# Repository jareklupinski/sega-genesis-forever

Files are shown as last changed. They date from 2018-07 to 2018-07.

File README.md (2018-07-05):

# sega-genesis-forever
A Standalone Sega Genesis music player using native hardware

Using an ATSAMD21 microcontroller, this gadget reads Sega Genesis VGM files from a microSD card and plays them back using the same sound chips that were used in the original Sega Genesis. Even the audio path is cloned from original schematics!

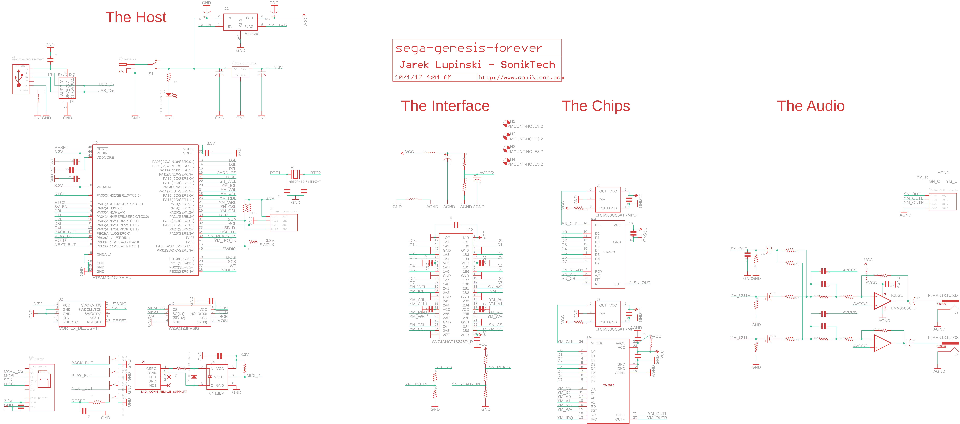
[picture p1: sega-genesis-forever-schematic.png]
schematic

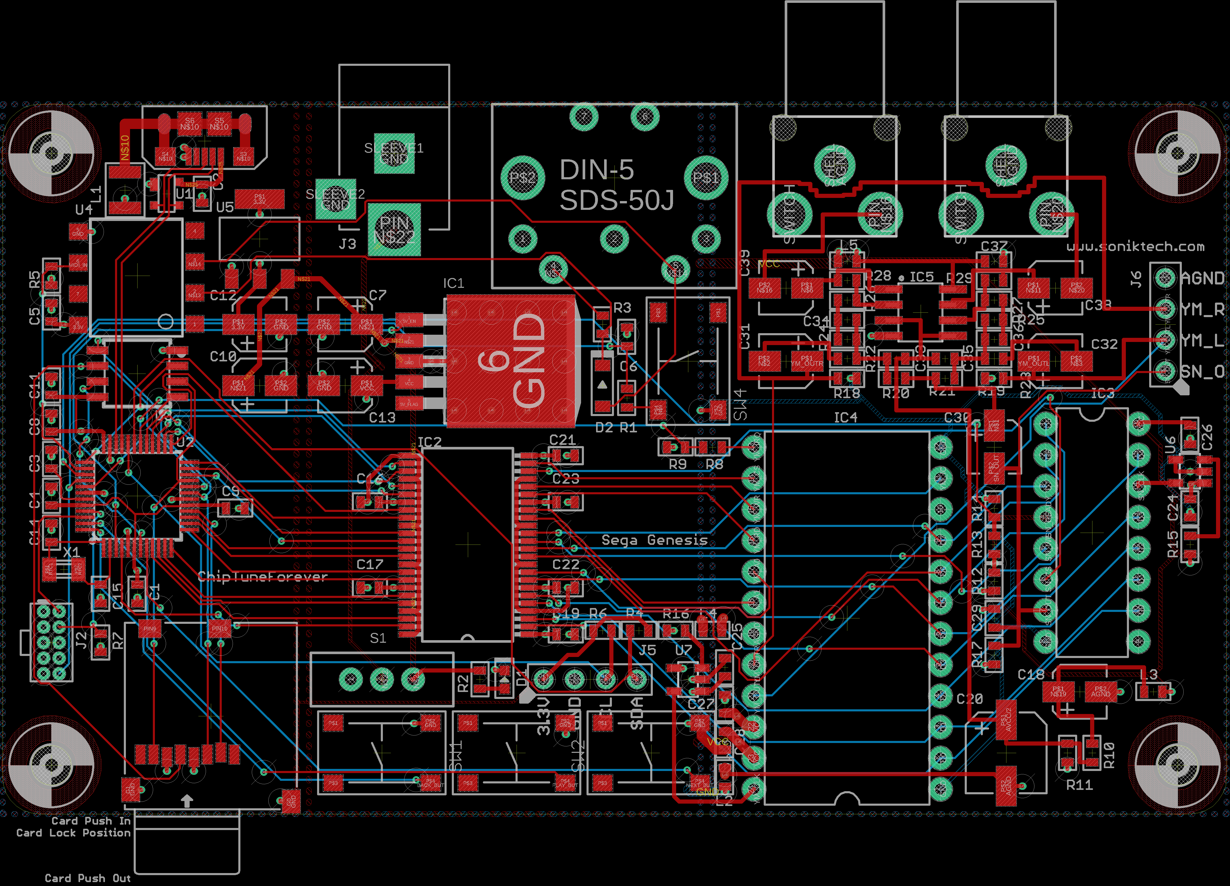
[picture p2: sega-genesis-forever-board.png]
board


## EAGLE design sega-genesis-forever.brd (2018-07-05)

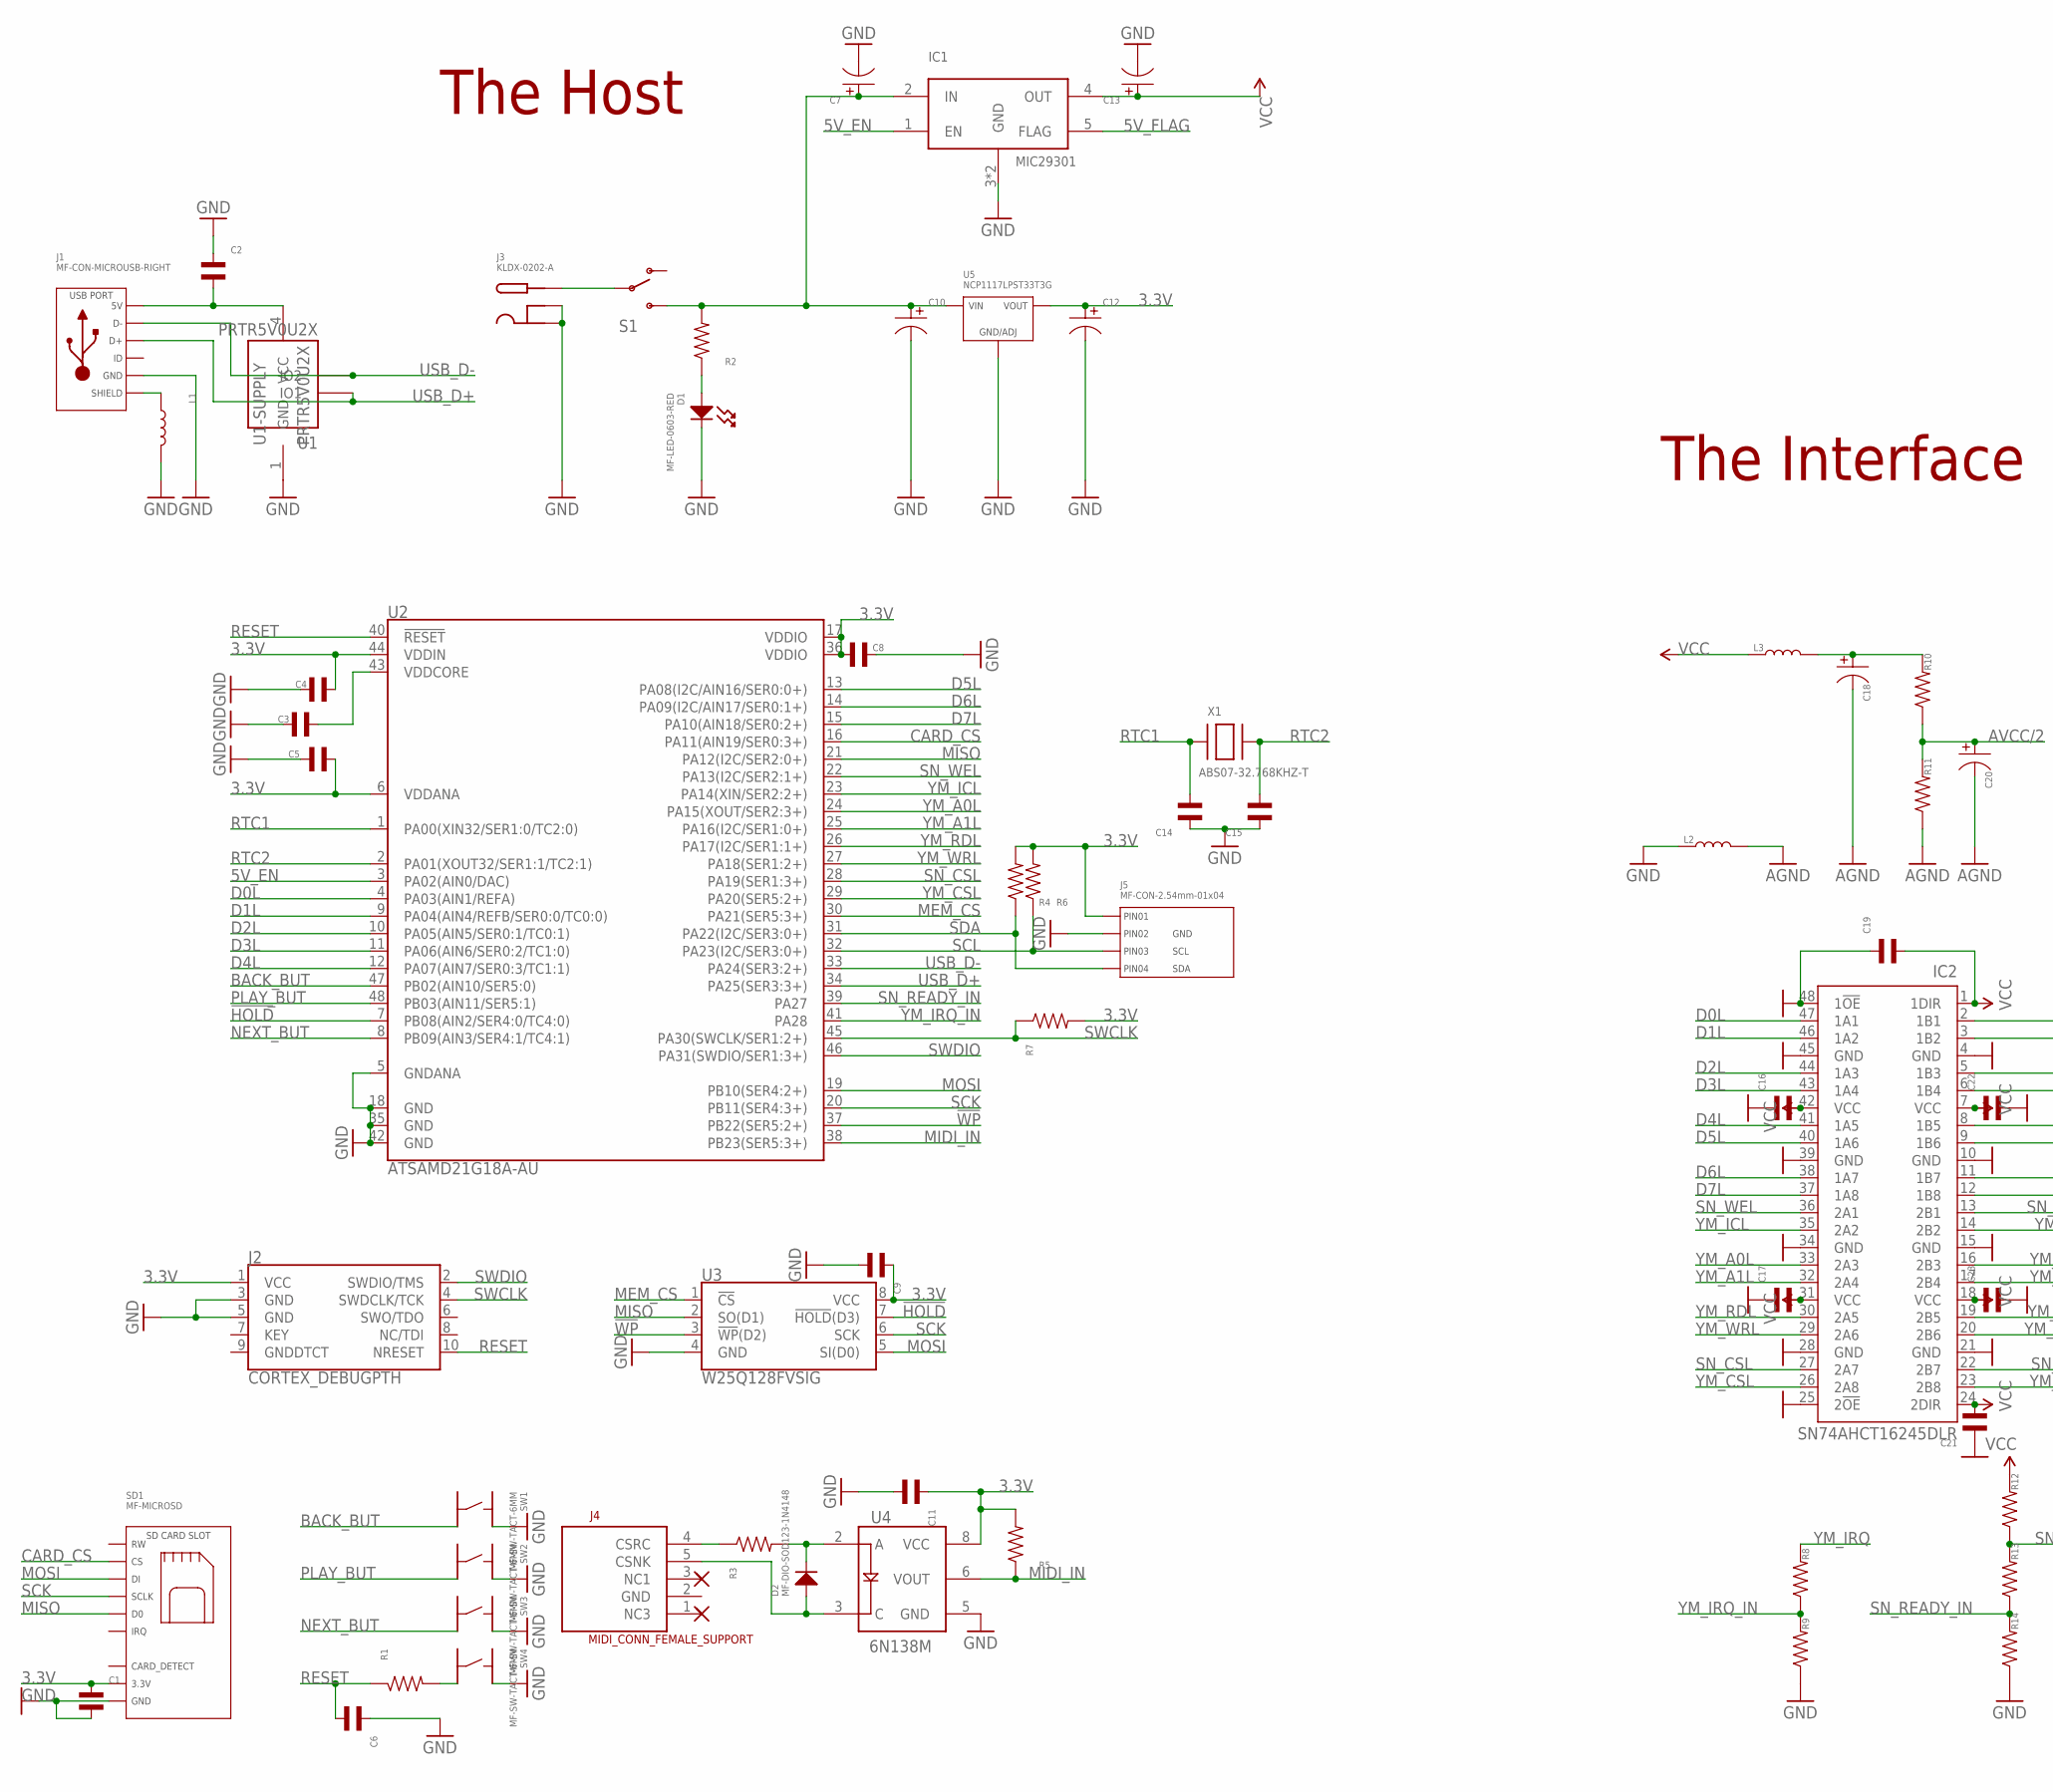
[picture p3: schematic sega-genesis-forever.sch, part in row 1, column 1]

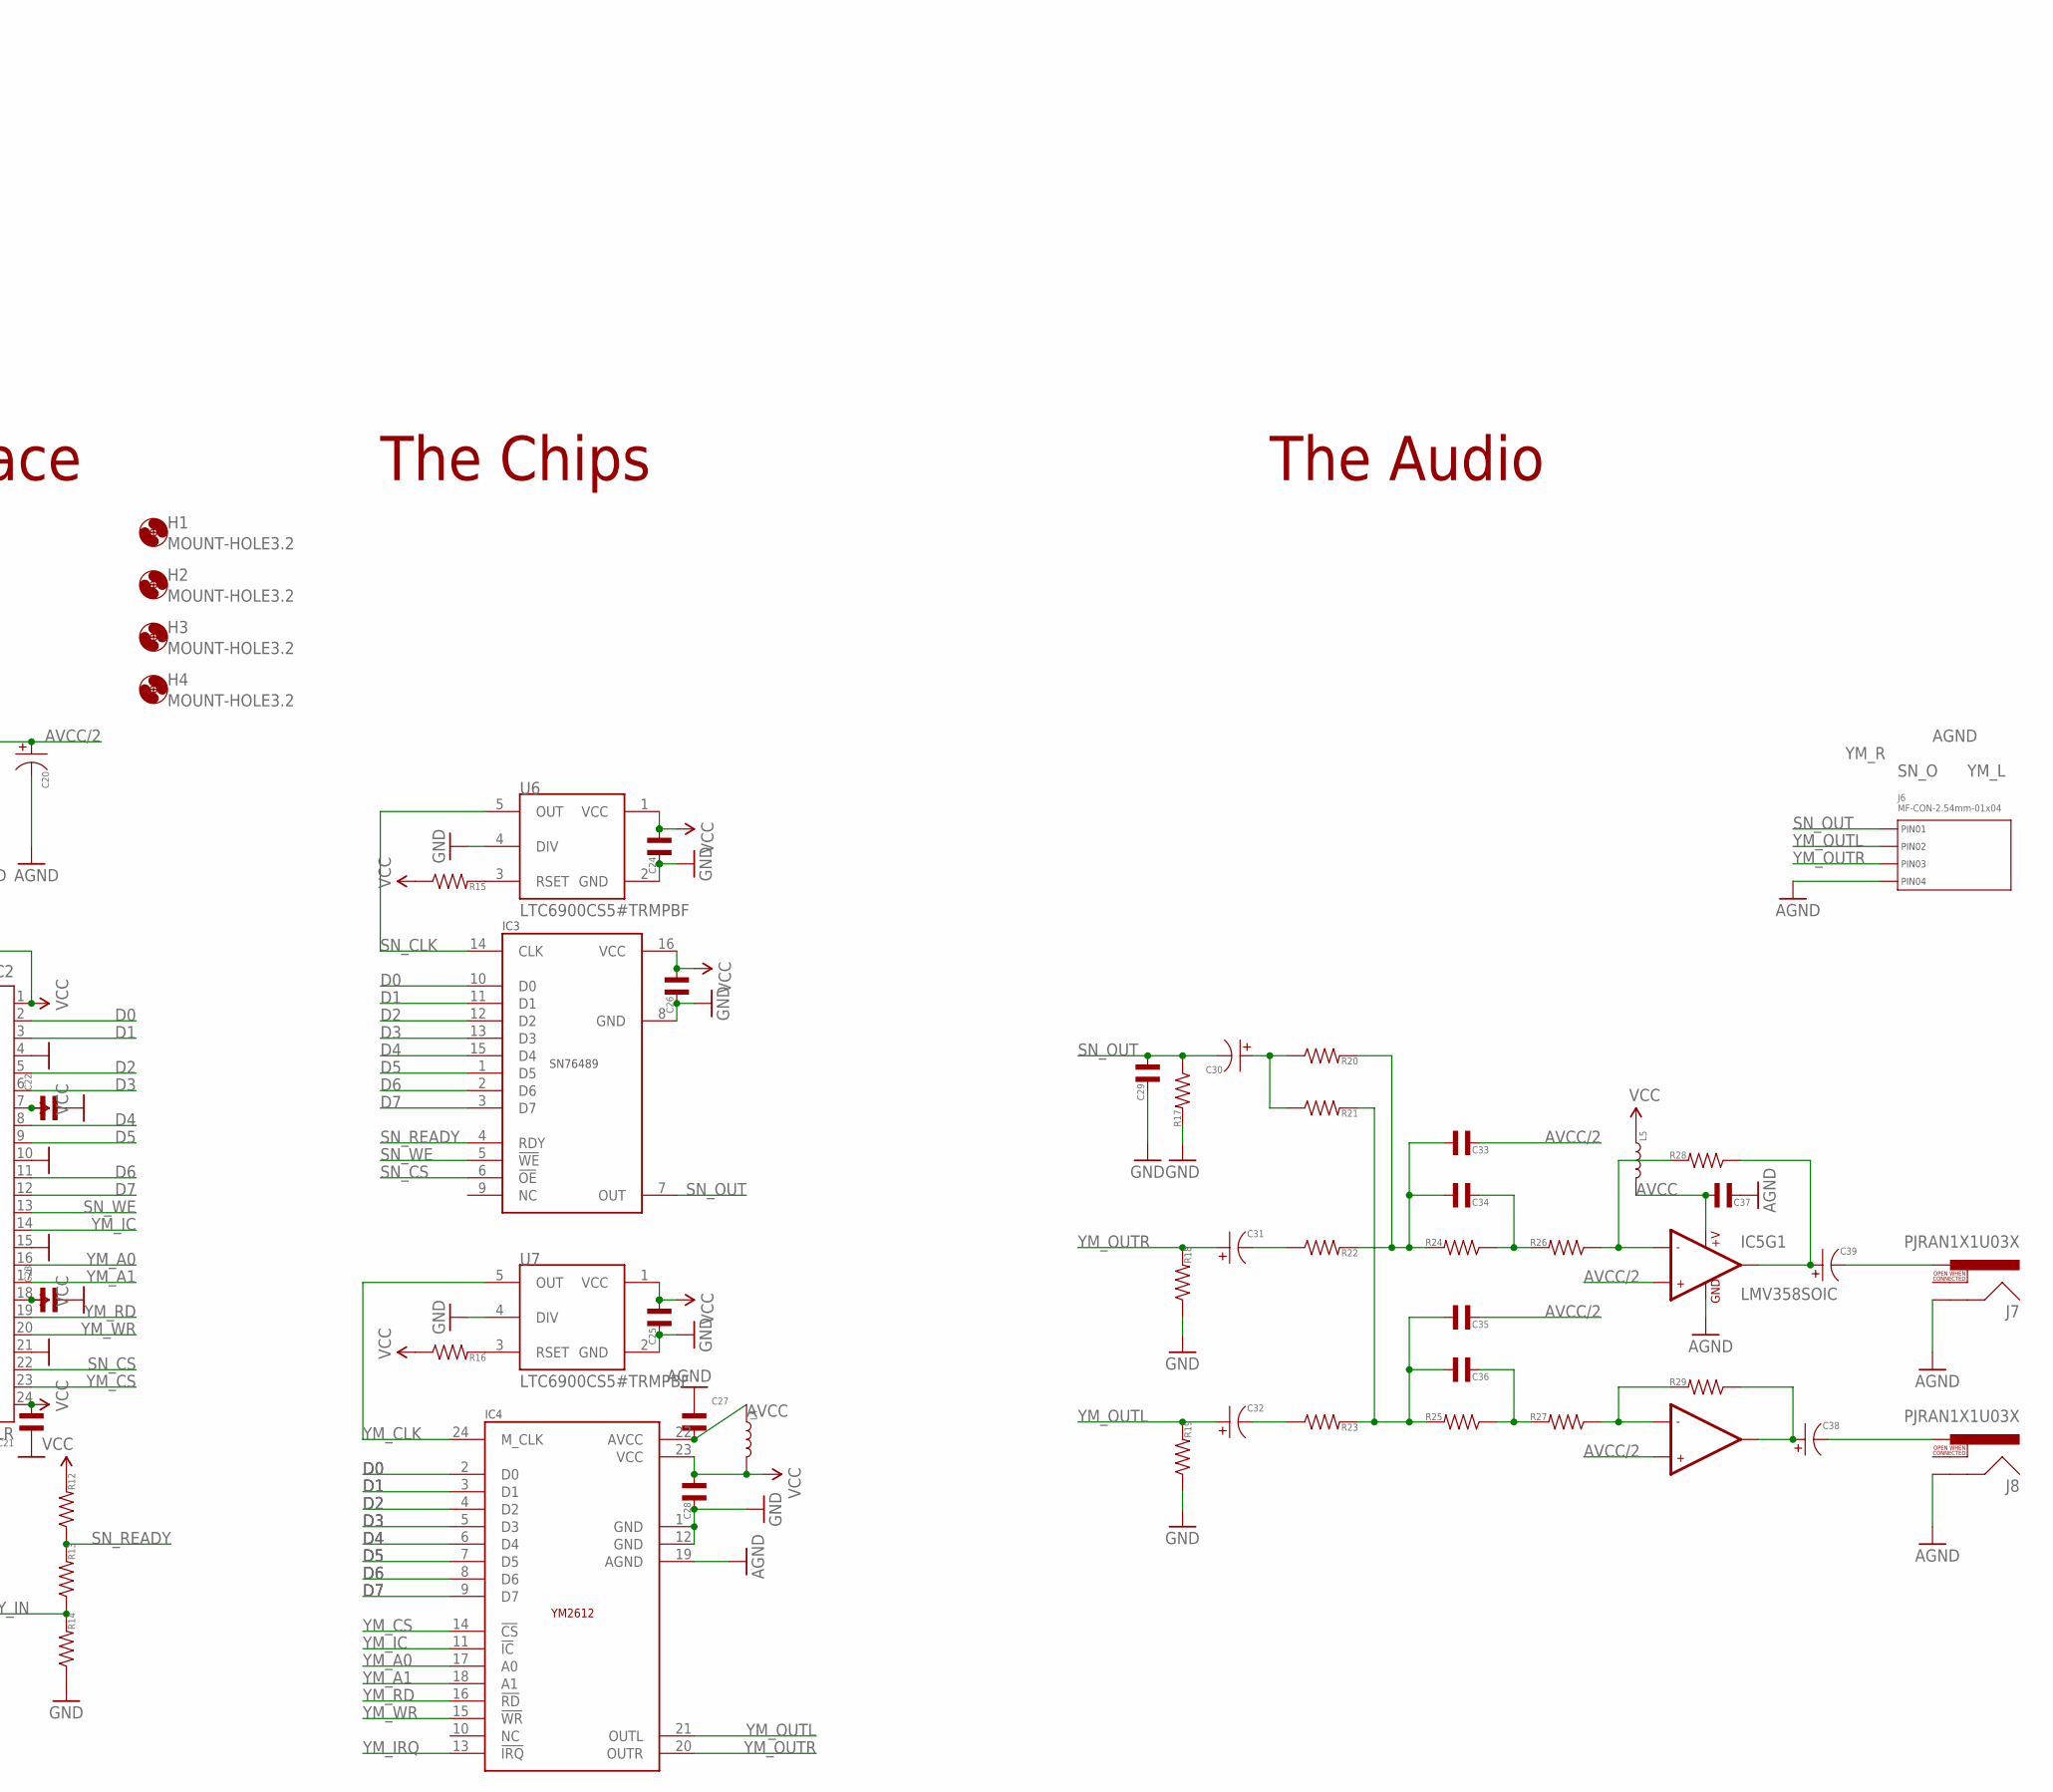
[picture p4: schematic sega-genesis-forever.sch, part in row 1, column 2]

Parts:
C1, C2, C3, C4, C5, C6, C8, C9, C11, C14, C15, C16, C17, C19, C21, C22, C23, C24, C25, C26, C27, C28, C29, C33, C34, C35, C36, C37: CAPACITOR_NP_0603; C0603
C7, C10, C12, C13, C18, C30, C31, C32, C38, C39: CAPACITOR_P_4MM; CP4MM
C20: CAPACITOR_P_6.3MM; CP6.3MM
D1: MF-LED-0603-RED; LED0603
D2: MF-DIO-SOD123-1N4148; SOD-123
H1, H2, H3, H4: MOUNT-HOLE3.2; 3,2
IC1: MIC29301; TO263-5
IC2: SN74AHCT16245DLR; DL_R-PDSO-G48
IC3: ED16DT; DIL16-EZ
IC4: ED24DT; DIL24-EZ
IC5: LMV358SOIC; SO08
J1: MF-CON-MICROUSB-RIGHT; MICROUSB-RIGHT
J2: CORTEX_DEBUGPTH; 2X5-PTH-1.27MM
J3: KLDX-0202-A; DC_PWR_JACK
J4: MIDI_CONN_FEMALE_SUPPORT; DIN_5_FEMALE_SUPPORT
J5, J6: MF-CON-2.54mm-01x04; PTH_2.54MM_01X04
J7, J8: PJRAN1X1U03X; RCA
L1: INDUCTOR_1210; L1210
L2, L3, L4, L5: INDUCTOR_0603; L0603
R1, R2, R3, R4, R5, R6, R7, R8, R9, R10, R11, R12, R13, R14, R15, R16, R17, R18, R19, R20, R21, R22, R23, R24, R25, R26, R27, R28, R29: RESISTOR_0603; R0603
S1: SWITCH-SPDTPTH; SWITCH-SPDT
SD1: MF-MICROSD
SW1, SW2, SW3, SW4: MF-SW-TACT-6MM; TACT6MM
U1: PRTR5V0U2X; SOT-143B
U2: ATSAMD21G18A-AU; TQFP-48
U3: W25Q128FVSIG; SOIC-8
U4: 6N138M; 8-SMD
U5: NCP1117LPST33T3G; SOT-223-3
U6, U7: LTC6900CS5#TRMPBF; TSOT23-5L
X1: ABS07-32.768KHZ-T; XTAL3215

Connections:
3.3V: C1.P$1, C4.P$2, C5.P$2, C8.P$2, C9.P$1, C11.P$1, C12.P$1, J2.1 (VCC), J5.P$1 (PIN1), R4.P$2, R5.P$2, R6.P$2, R7.P$2, SD1.PIN4 (3.3V), U2.6 (VDDANA), U2.17 (VDDIO), U2.36 (VDDIO), U2.44 (VDDIN), U3.8 (VCC), U4.8 (VCC), U5.P$1 (VOUT), U5.P$3 (VOUT)
5V_EN: IC1.1 (EN), U2.3 (PA02(AIN0/DAC))
5V_FLAG: IC1.5 (FLAG)
!HOLD: U2.7 (PB08(AIN2/SER4:0/TC4:0)), U3.7 (!HOLD!(D3))
!WP: U2.37 (PB22(SER5:2+)), U3.3 (!WP!(D2))
AGND: C18.P$2, C20.P$2, C27.P$1, C37.P$2, IC4.19 (AGND), IC5.4 (GND), J6.P$4 (PIN4), J7.SHELL, J8.SHELL, L2.P$2, R11.P$1
AVCC: C27.P$2, C37.P$1, IC4.22 (AVCC), IC5.8 (+V), L4.P$1, L5.P$2
AVCC/2: C20.P$1, C33.P$2, C35.P$2, IC5.3 (+IN1), IC5.5 (+IN2), R10.P$1, R11.P$2
BACK_BUT: SW1.P$4, U2.47 (PB02(AIN10/SER5:0))
CARD_CS: SD1.PIN2 (CS), U2.16 (PA11(AIN19/SER0:3+))
D0: IC2.2 (1B1), IC3.10 (D0), IC4.2 (D0)
D0L: IC2.47 (1A1), U2.4 (PA03(AIN1/REFA))
D1: IC2.3 (1B2), IC3.11 (D1), IC4.3 (D1)
D1L: IC2.46 (1A2), U2.9 (PA04(AIN4/REFB/SER0:0/TC0:0))
D2: IC2.5 (1B3), IC3.12 (D2), IC4.4 (D2)
D2L: IC2.44 (1A3), U2.10 (PA05(AIN5/SER0:1/TC0:1))
D3: IC2.6 (1B4), IC3.13 (D3), IC4.5 (D3)
D3L: IC2.43 (1A4), U2.11 (PA06(AIN6/SER0:2/TC1:0))
D4: IC2.8 (1B5), IC3.15 (D4), IC4.6 (D4)
D4L: IC2.41 (1A5), U2.12 (PA07(AIN7/SER0:3/TC1:1))
D5: IC2.9 (1B6), IC3.1 (D5), IC4.7 (D5)
D5L: IC2.40 (1A6), U2.13 (PA08(I2C/AIN16/SER0:0+))
D6: IC2.11 (1B7), IC3.2 (D6), IC4.8 (D6)
D6L: IC2.38 (1A7), U2.14 (PA09(I2C/AIN17/SER0:1+))
D7: IC2.12 (1B8), IC3.3 (D7), IC4.9 (D7)
D7L: IC2.37 (1A8), U2.15 (PA10(AIN18/SER0:2+))
GND: C1.P$2, C2.P$1, C3.P$2, C4.P$1, C5.P$1, C6.P$1, C7.P$2, C8.P$1, C9.P$2, C10.P$2, C11.P$2, C12.P$2, C13.P$2, C14.P$1, C15.P$1, C16.P$1, C17.P$1, C19.P$1, C21.P$1, C22.P$2, C23.P$2, C24.P$2, C25.P$2, C26.P$2, C28.P$2, C29.P$2, D1.CATHODE, IC1.3 (GND), IC1.6 (GND), IC2.4 (GND), IC2.10 (GND), IC2.15 (GND), IC2.21 (GND), IC2.25 (2!OE), IC2.28 (GND), IC2.34 (GND), IC2.39 (GND), IC2.45 (GND), IC2.48 (1!OE), IC3.8 (GND), IC4.1 (GND), IC4.12 (GND), J1.5 (GND), J2.3 (GND), J2.5 (GND), J3.SLEEVE1 (SLEEVE), J3.SLEEVE2 (SLEEVE_SHUNT), J5.P$2 (PIN2), L1.P$2, L2.P$1, R9.P$1, R14.P$1, R17.P$2, R18.P$1, R19.P$1, SD1.G0 (GND), SD1.G1 (GND), SD1.PIN6 (GND), SW1.P$2, SW2.P$2, SW3.P$2, SW4.P$2, U1.1 (GND), U2.5 (GNDANA), U2.18 (GND), U2.35 (GND), U2.42 (GND), U3.4 (GND), U4.5 (GND), U5.P$2 (GND/ADJ), U6.2 (GND), U6.4 (DIV), U7.2 (GND), U7.4 (DIV)
LADC: IC5.6 (-IN2), R27.P$1, R29.P$2
MEM_CS: U2.30 (PA21(SER5:3+)), U3.1 (!CS!)
MIDI_IN: R5.P$1, U2.38 (PB23(SER5:3+)), U4.6 (VOUT)
MISO: SD1.PIN7 (D0), U2.21 (PA12(I2C/SER2:0+)), U3.2 (SO(D1))
MOSI: SD1.PIN3 (DI), U2.19 (PB10(SER4:2+)), U3.5 (SI(D0))
unnamed: C30.P$1, R20.P$1, R21.P$1
unnamed: C31.P$2, R22.P$1
unnamed: C32.P$2, R23.P$1
unnamed: C33.P$1, C34.P$1, R20.P$2, R22.P$2, R24.P$2
unnamed: C35.P$1, C36.P$1, R21.P$2, R23.P$2, R25.P$2
unnamed: C39.P$1, IC5.1 (OUT1), R28.P$1
unnamed: J4.4 (CSRC), R3.P$1
unnamed: C3.P$1, U2.43 (VDDCORE)
unnamed: R1.P$2, SW4.P$4
unnamed: J1.S1 (SLD), J1.S2 (SLD), J1.S3 (SLD), J1.S4 (SLD), J1.S5 (SLD), J1.S6 (SLD), L1.P$1
unnamed: C38.P$1, IC5.7 (OUT2), R29.P$1
unnamed: C34.P$2, R24.P$1, R26.P$2
unnamed: D2.CATHODE, R3.P$2, U4.2 (A)
unnamed: D2.ANODE, J4.5 (CSNK), U4.3 (C)
unnamed: C39.P$2, J7.PIN
unnamed: C36.P$2, R25.P$1, R27.P$2
unnamed: D1.ANODE, R2.P$1
unnamed: C18.P$1, L3.P$2, R10.P$2
unnamed: C38.P$2, J8.PIN
unnamed: C7.P$1, C10.P$1, IC1.2 (IN), R2.P$2, S1.3 (S), U5.P$4 (VIN)
unnamed: J3.PIN, S1.2
unnamed: R16.P$2, U7.3 (RSET)
unnamed: R15.P$2, U6.3 (RSET)
unnamed: C2.P$2, J1.1 (5V), U1.4 (VCC)
NEXT_BUT: SW3.P$4, U2.8 (PB09(AIN3/SER4:1/TC4:1))
PLAY_BUT: SW2.P$4, U2.48 (PB03(AIN11/SER5:1))
RADC: IC5.2 (-IN1), R26.P$1, R28.P$2
RESET: C6.P$2, J2.10 (NRESET), R1.P$1, U2.40 (!RESET!)
RTC1: C14.P$2, U2.1 (PA00(XIN32/SER1:0/TC2:0)), X1.P$1
RTC2: C15.P$2, U2.2 (PA01(XOUT32/SER1:1/TC2:1)), X1.P$2
SCK: SD1.PIN5 (SCLK), U2.20 (PB11(SER4:3+)), U3.6 (SCK)
SCL: J5.P$3 (PIN3), R6.P$1, U2.32 (PA23(I2C/SER3:0+))
SDA: J5.P$4 (PIN4), R4.P$1, U2.31 (PA22(I2C/SER3:0+))
SN_CLK: IC3.14 (CLK), U6.5 (OUT)
SN_CS: IC2.22 (2B7), IC3.6 (!OE)
SN_CSL: IC2.27 (2A7), U2.28 (PA19(SER1:3+))
SN_OUT: C29.P$1, C30.P$2, IC3.7 (OUT), J6.P$1 (PIN1), R17.P$1
SN_READY: IC3.4 (RDY), R12.P$1, R13.P$2
SN_READY_IN: R13.P$1, R14.P$2, U2.39 (PA27)
SN_WE: IC2.13 (2B1), IC3.5 (!WE)
SN_WEL: IC2.36 (2A1), U2.22 (PA13(I2C/SER2:1+))
SWCLK: J2.4 (SWDCLK/TCK), R7.P$1, U2.45 (PA30(SWCLK/SER1:2+))
SWDIO: J2.2 (SWDIO/TMS), U2.46 (PA31(SWDIO/SER1:3+))
USB_D+: J1.3 (D+), U1.2 (IO1), U2.34 (PA25(SER3:3+))
USB_D-: J1.2 (D-), U1.3 (IO2), U2.33 (PA24(SER3:2+))
VCC: C13.P$1, C16.P$2, C17.P$2, C19.P$2, C21.P$2, C22.P$1, C23.P$1, C24.P$1, C25.P$1, C26.P$1, C28.P$1, IC1.4 (OUT), IC2.1 (1DIR), IC2.7 (VCC), IC2.18 (VCC), IC2.24 (2DIR), IC2.31 (VCC), IC2.42 (VCC), IC3.16 (VCC), IC4.23 (VCC), L3.P$1, L4.P$2, L5.P$1, R12.P$2, R15.P$1, R16.P$1, U6.1 (VCC), U7.1 (VCC)
YM_A0: IC2.16 (2B3), IC4.17 (A0)
YM_A0L: IC2.33 (2A3), U2.24 (PA15(XOUT/SER2:3+))
YM_A1: IC2.17 (2B4), IC4.18 (A1)
YM_A1L: IC2.32 (2A4), U2.25 (PA16(I2C/SER1:0+))
YM_CLK: IC4.24 (M_CLK), U7.5 (OUT)
YM_CS: IC2.23 (2B8), IC4.14 (!CS)
YM_CSL: IC2.26 (2A8), U2.29 (PA20(SER5:2+))
YM_IC: IC2.14 (2B2), IC4.11 (!IC)
YM_ICL: IC2.35 (2A2), U2.23 (PA14(XIN/SER2:2+))
YM_IRQ: IC4.13 (!IRQ), R8.P$2
YM_IRQ_IN: R8.P$1, R9.P$2, U2.41 (PA28)
YM_OUTL: C32.P$1, IC4.21 (OUTL), J6.P$2 (PIN2), R19.P$2
YM_OUTR: C31.P$1, IC4.20 (OUTR), J6.P$3 (PIN3), R18.P$2
YM_RD: IC2.19 (2B5), IC4.16 (!RD)
YM_RDL: IC2.30 (2A5), U2.26 (PA17(I2C/SER1:1+))
YM_WR: IC2.20 (2B6), IC4.15 (!WR)
YM_WRL: IC2.29 (2A6), U2.27 (PA18(SER1:2+))

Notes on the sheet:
The Host
The Interface
The Chips
The Audio

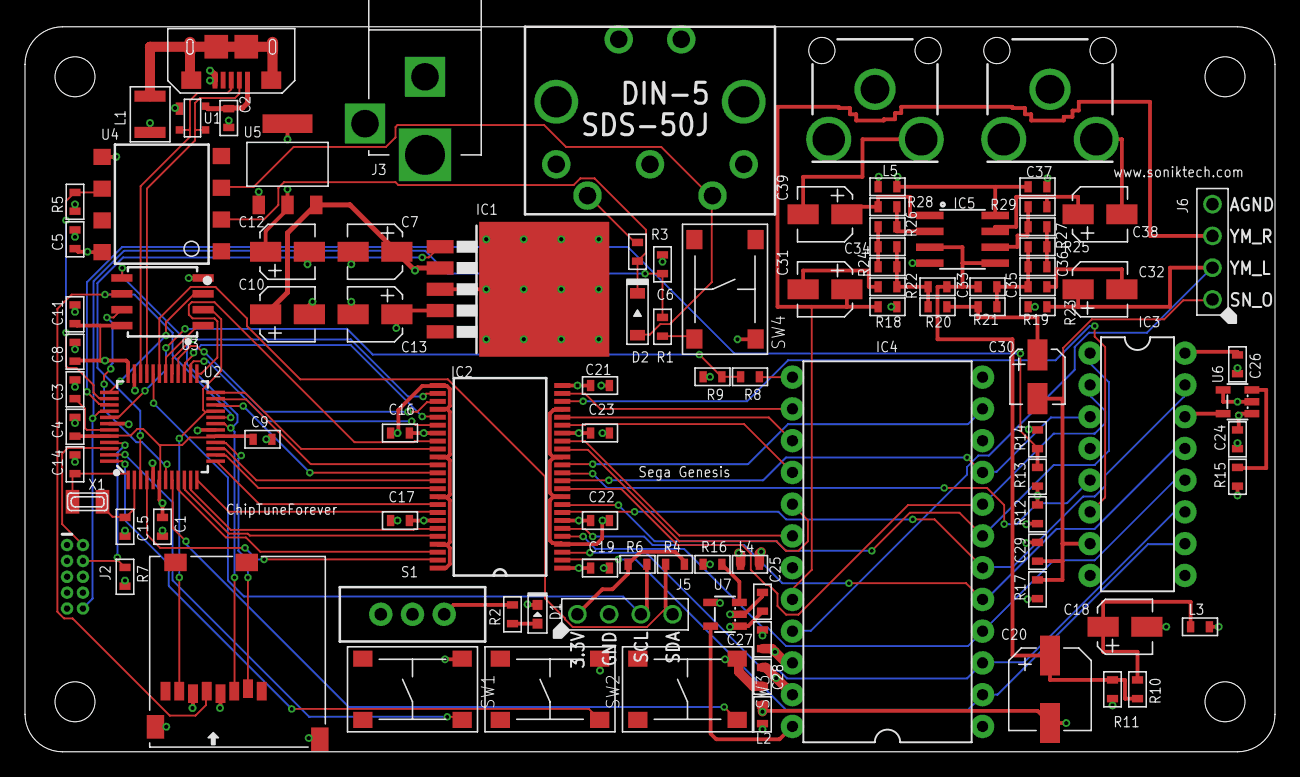
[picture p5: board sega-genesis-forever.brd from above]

Board: 4 copper layers, 100.0 x 58.0 mm, 106 parts (0 on the bottom side), 94 nets.

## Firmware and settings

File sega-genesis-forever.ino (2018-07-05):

#include <SPI.h>
#include <SdFat.h>
#include <SPIFlash.h>
#include <Wire.h>
#include <Fatlib/FatFile.h>
#include <Adafruit_GFX.h>
#include <Adafruit_SSD1306.h>
#define SPI_SPEED SD_SCK_MHZ(50)
#define NOP __asm__ __volatile__ ("nop\n\t")
/*
   struct bmp_file_header_t {
  uint16_t signature;
  uint32_t file_size;
  uint16_t reserved[2];
  uint32_t image_offset;
  };

  struct bmp_image_header_t {
  uint32_t header_size;
  uint32_t image_width;
  uint32_t image_height;
  uint16_t color_planes;
  uint16_t bits_per_pixel;
  uint32_t compression_method;
  uint32_t image_size;
  uint32_t horizontal_resolution;
  uint32_t vertical_resolution;
  uint32_t colors_in_palette;
  uint32_t important_colors;
  };

  bmp_file_header_t fileHeader;
  bmpImage.read(&fileHeader, sizeof(fileHeader));

  bmp_image_header_t imageHeader;
  bmpImage.read(&imageHeader, sizeof(imageHeader));

   bmpImage.seek(fileHeader.image_offset);


*/



//#define DEBUG

//EEPROM COMMANDS
#define MANID        0x90
#define PAGEPROG     0x02
#define READDATA     0x03
#define READSTAT1    0x05
#define WRITEENABLE  0x06
#define GLOBALUNLOCK 0x98
#define SUSPEND      0x75
#define RESUME       0x7A
#define JEDECID      0x9f
#define RELEASE      0xAB
#define BLOCK64ERASE 0xD8
//PORTA
#define CARD_CS ( 1 << 11 ) // 0
#define MISO    ( 1 << 12 ) // 0
#define SN_WE   ( 1 << 13 ) // 1
#define YM_IC   ( 1 << 14 ) // 1
#define YM_A0   ( 1 << 15 ) // 0
#define YM_A1   ( 1 << 16 ) // 0
#define YM_RD   ( 1 << 17 ) // 1
#define YM_WR   ( 1 << 18 ) // 1
#define SN_CS   ( 1 << 19 ) // 1
#define YM_CS   ( 1 << 20 ) // 1
#define MEM_CS  ( 1 << 21 ) // 1
#define SDA     ( 1 << 22 ) // 1
#define SCL     ( 1 << 23 ) // 1
#define SN_RDY  ( 1 << 27 ) // 1
#define YM_IRQ  ( 1 << 28 ) // 1
//PORTB
#define BACKBUTTON        ( 1 << 2 ) // 1
#define BACKARDUINO       19
#define PLAYBUTTON        ( 1 << 3 ) // 1
#define PLAYARDUINO       25
#define HOLD              ( 1 << 8 ) // 0
#define NEXTBUTTON        ( 1 << 9 ) // 1
#define NEXTARDUINO       16
#define MOSI              ( 1 << 10 ) // 0
#define SCK               ( 1 << 11 ) // 0
#define MEM_WP            ( 1 << 22 ) // 1
#define MIDI_IN           ( 1 << 23 ) // 1
//DEBUG
#ifdef DEBUG
#define DEBUG_PRINT(...)   Serial.print(__VA_ARGS__)
#define DEBUG_PRINTLN(...) Serial.println(__VA_ARGS__)
#else
#define DEBUG_PRINT(...)
#define DEBUG_PRINTLN(...)
#endif

SdFat SD;
FatFile vgmDir;
FatFile vgmFile;
StdioStream vgmStream;
Adafruit_SSD1306 display;
volatile uint32_t pause;
volatile uint8_t backButtonFlag;
volatile uint8_t playButtonFlag;
volatile uint8_t nextButtonFlag;
#define RAMBUFFERSIZE 19000
uint8_t pcmBuffer[ RAMBUFFERSIZE ];
uint8_t ramBufferFlag;

char fileNameBuf[ 256 ];
uint8_t nextSongFlag = 0;
uint32_t numFiles;
uint32_t vgmStreamPosition = 0;
uint32_t pcmPosition = 0;
uint32_t pcmPositionOffset = 0;
uint32_t ident = 0;
uint32_t eof = 0;
uint32_t vers = 0;
uint32_t snclk = 0;
uint32_t ymclk = 0;
uint32_t gd3Offset = 0;
uint32_t totalSamples = 0;
uint32_t loopOffset = 0;
uint32_t loopSamples = 0;
uint32_t rateHz = 0;
uint32_t snFeedback = 0;
uint32_t snShiftReg = 0;
uint32_t snFlags = 0;
uint32_t ym2612Clock = 0;
uint32_t ym2151Clock = 0;
uint32_t vgmDataOffset = 0;

void TC3_Handler(void) {
  TcCount16* TC = (TcCount16*) TC3;
  if ( TC->INTFLAG.bit.MC0 == 1 ) {
    if ( pause ) pause--;
    TC->INTFLAG.bit.MC0 = 1;
  }
}

void backButtonTrigger() {
  backButtonFlag = 1;
}

void playButtonTrigger() {
  playButtonFlag = 1;
}
void nextButtonTrigger() {
  nextButtonFlag = 1;
}

void writeEnable() {
  PORT->Group[PORTA].OUTCLR.reg = MEM_CS;
  SPI.transfer( WRITEENABLE );
  PORT->Group[PORTA].OUTSET.reg = MEM_CS;
}

void waitForFlashReady() {
  PORT->Group[PORTA].OUTCLR.reg = MEM_CS;
  SPI.transfer( READSTAT1 );
  while ( SPI.transfer( 0x00 ) & 0x01 ) {
    DEBUG_PRINT( "." );
  }
  PORT->Group[PORTA].OUTSET.reg = MEM_CS;
}

void dumpPcmToFlash( uint32_t bytes ) {
  uint8_t buf[ 256 ];
  uint32_t i = 0;
  uint32_t y = 0;
  while ( i < bytes ) {
    writeEnable();
    waitForFlashReady();
    DEBUG_PRINTLN( "Erasing 64K Block Starting At " + String( i, HEX ));
    PORT->Group[PORTA].OUTCLR.reg = MEM_CS;
    SPI.transfer( BLOCK64ERASE );
    SPI.transfer( i >> 16 );
    SPI.transfer( i >> 8 );
    SPI.transfer( 0 );
    PORT->Group[PORTA].OUTSET.reg = MEM_CS;
    waitForFlashReady();
    for ( int page = 0; page < 256; page++ ) {
      for ( int j = 0; j < 256; j++ ) {
        if ( y < ( bytes ) ) buf[ j ] = vgmStream.getc();
        else buf[ j ] = 0xFF;
        y++;
      }
      writeEnable();
      waitForFlashReady();
      PORT->Group[PORTA].OUTCLR.reg = MEM_CS;
      SPI.transfer( PAGEPROG );
      SPI.transfer( i >> 16 );
      SPI.transfer( i >> 8 );
      SPI.transfer( i );
      for ( int k = 0; k < 256; k++ ) {
        SPI.transfer( buf[ k ] );
        i++;
      }
      PORT->Group[PORTA].OUTSET.reg = MEM_CS;
      waitForFlashReady();
      DEBUG_PRINTLN( "Wrote to flash page " + String( i, HEX ) );
    }
  }
  DEBUG_PRINTLN( "Verifying:" );
  //for ( uint32_t k = 0; k < bytes; k++ ) { DEBUG_PRINT( readFromFlash( k ), HEX ); } PORT->Group[PORTB].OUTSET.reg = HOLD;
  PORT->Group[PORTA].OUTSET.reg = MEM_CS;
  DEBUG_PRINTLN( "" );
}
byte readFromFlash( uint32_t addr ) {
  byte data;
  static uint32_t lastAddr = 0xFFFFFFF0;
  if ( ramBufferFlag ) {
    data = pcmBuffer[ addr ];
  }
  else {
    PORT->Group[PORTB].OUTSET.reg = HOLD;
    PORT->Group[PORTA].OUTCLR.reg = MEM_CS;
    if ( addr != ( lastAddr + 1 )) {
      DEBUG_PRINT( "Last Address was " + String( lastAddr, HEX ) + " Changing Address to " + String( addr, HEX ) + " | ");
      PORT->Group[PORTA].OUTSET.reg = MEM_CS;
      PORT->Group[PORTA].OUTCLR.reg = MEM_CS;
      SPI.transfer( READDATA );
      SPI.transfer( addr >> 16 );
      SPI.transfer( addr >> 8 );
      SPI.transfer( addr );
    }
    data = SPI.transfer( 0 );
    PORT->Group[PORTB].OUTCLR.reg = HOLD;
    lastAddr = addr;
  }
  return data;
}

void playSNdata( uint8_t data ) {
  DEBUG_PRINTLN( "SN 0x" + String( data, HEX ));
  PORT->Group[PORTA].OUTCLR.reg = SN_CS;
  PORT->Group[PORTA].OUTSET.reg = data << 3;
  PORT->Group[PORTA].OUTCLR.reg = ( ~( data ) & 0xFF ) << 3;
  PORT->Group[PORTA].OUTCLR.reg = SN_WE;
  while ( !(PORT->Group[PORTA].IN.reg & SN_RDY ));
  PORT->Group[PORTA].OUTSET.reg = SN_WE;
  PORT->Group[PORTA].OUTSET.reg = SN_CS;
}

void playYMdata( uint8_t port, uint8_t addr, uint8_t data ) {
  DEBUG_PRINTLN( "YM" + String( port ) + " 0x" + String( addr, HEX ) + " 0x" + String( data, HEX ) );
  PORT->Group[PORTA].OUTCLR.reg = YM_CS;
  PORT->Group[PORTA].OUTCLR.reg = YM_A0;
  if ( port ) PORT->Group[PORTA].OUTSET.reg = YM_A1;
  else PORT->Group[PORTA].OUTCLR.reg = YM_A1;
  PORT->Group[PORTA].OUTSET.reg = ( addr << 3 );
  PORT->Group[PORTA].OUTCLR.reg = ( ~( addr ) & 0xFF ) << 3;
  PORT->Group[PORTA].OUTCLR.reg = YM_WR;
  for ( int i = 0; i < 9; i++ ) NOP;
  PORT->Group[PORTA].OUTSET.reg = YM_WR;
  PORT->Group[PORTA].OUTSET.reg = YM_A0;
  PORT->Group[PORTA].OUTSET.reg = ( data << 3 );
  PORT->Group[PORTA].OUTCLR.reg = ( ~( data ) & 0xFF ) << 3;
  PORT->Group[PORTA].OUTCLR.reg = YM_WR;
  for ( int i = 0; i < 9; i++ ) NOP;
  PORT->Group[PORTA].OUTSET.reg = YM_WR;
  PORT->Group[PORTA].OUTSET.reg = YM_CS;
}

void updateDisplay() {
  display.clearDisplay();
  display.setCursor(0, 0);
  display.println("Now Playing");
  display.println("");
  display.println(String( fileNameBuf ));
  display.println(String( pcmPosition ));
  display.display();
}

typedef void ( *jumpTable )( void );
void nogo( void ) {}
void playSN() {
  uint8_t data = vgmStream.getc();
  playSNdata( data );
}
void playYM( uint8_t port ) {
  uint8_t addr = vgmStream.getc();
  uint8_t data = vgmStream.getc();
  playYMdata( port, addr, data );
}
void playYM1() {
  playYM( 1 );
}
void playYM0() {
  playYM( 0 );
}
void waitNSamples( uint32_t n ) {
  if (n) n--;
  pause = n;
  DEBUG_PRINTLN( "DL " + String( n ));
}
void waitSamples() {
  uint32_t n = vgmStream.getc();
  n += uint16_t( vgmStream.getc() ) << 8;
  waitNSamples( n );
}
void endOfFile() {
  if ( loopOffset ) {
    vgmStream.fseek( loopOffset + 0x1C, SEEK_SET );
    loopOffset = 0;
  }
  else nextSongFlag = 1;
  DEBUG_PRINTLN( "EOL 0x66" );
}
void pcmStream() {
  uint8_t addr = vgmStream.getc(); //0x66
  uint8_t data = vgmStream.getc(); //Data Block Type
  uint32_t s;
  if ( data < 0x40 ) {
    s += uint32_t( vgmStream.getc() ) << ( 8 * 0 );
    s += uint32_t( vgmStream.getc() ) << ( 8 * 1 );
    s += uint32_t( vgmStream.getc() ) << ( 8 * 2 );
    s += uint32_t( vgmStream.getc() ) << ( 8 * 3 );
    Serial.println( "Data Block Type " + String( data, HEX ) + " Space Needed: " + s + " Set Command Pointer to " + String( s + vgmStream.ftell(), HEX ) );
    pcmPositionOffset = vgmStream.ftell();
    if ( s < RAMBUFFERSIZE ) {
      Serial.println( "Dumping to RAM" );
      for ( uint32_t i = 0; i < s; i++ ) {
        pcmBuffer[ i ] = vgmStream.getc();
      }
      ramBufferFlag = 1;
    }
    else {
      dumpPcmToFlash( s );
      ramBufferFlag = 0;
    }
  }
  else {
    Serial.println( "Error: Unsupported PCM Type " + String( data, HEX ) );
    nextSongFlag = 1;
  }
}
void playSample( uint32_t n ) {
  //if (n) n--;
  pause = n;
  uint8_t addr = 0x2A;
  uint8_t data = readFromFlash( pcmPosition );
  DEBUG_PRINT( "YM PCM 0x" + String( pcmPosition, HEX ) + " -> 0x" + String( pcmPosition + pcmPositionOffset, HEX) + " 0x" + String( data, HEX ) + " DL " + String( n ) + " | ");
  pcmPosition++;
  playYMdata( 0, addr, data );
}
void play0Sample() {
  playSample( 0 );
}
void play1Sample() {
  playSample( 1 );
}
void play2Sample() {
  playSample( 2 );
}
void play3Sample() {
  playSample( 3 );
}
void play4Sample() {
  playSample( 4 );
}
void play5Sample() {
  playSample( 5 );
}
void play6Sample() {
  playSample( 6 );
}
void play7Sample() {
  playSample( 7 );
}
void play8Sample() {
  playSample( 8 );
}
void play9Sample() {
  playSample( 9 );
}
void play10Sample() {
  playSample( 10 );
}
void play11Sample() {
  playSample( 11 );
}
void play12Sample() {
  playSample( 12 );
}
void play13Sample() {
  playSample( 13 );
}
void play14Sample() {
  playSample( 14 );
}
void play15Sample() {
  playSample( 15 );
}
void wait1Samples() {
  waitNSamples( 1 );
}
void wait2Samples() {
  waitNSamples( 2 );
}
void wait3Samples() {
  waitNSamples( 3 );
}
void wait4Samples() {
  waitNSamples( 4 );
}
void wait5Samples() {
  waitNSamples( 5 );
}
void wait6Samples() {
  waitNSamples( 6 );
}
void wait7Samples() {
  waitNSamples( 7 );
}
void wait8Samples() {
  waitNSamples( 8 );
}
void wait9Samples() {
  waitNSamples( 9 );
}
void wait10Samples() {
  waitNSamples( 10 );
}
void wait11Samples() {
  waitNSamples( 11 );
}
void wait12Samples() {
  waitNSamples( 12 );
}
void wait13Samples() {
  waitNSamples( 13 );
}
void wait14Samples() {
  waitNSamples( 14 );
}
void wait15Samples() {
  waitNSamples( 15 );
}
void wait16Samples() {
  waitNSamples( 16 );
}
void wait735Samples() {
  waitNSamples( 735 );
}
void wait882Samples() {
  waitNSamples( 882 );
}
void seekPCM() {
  uint32_t s;
  s += uint32_t( vgmStream.getc() ) << ( 8 * 0 );
  s += uint32_t( vgmStream.getc() ) << ( 8 * 1 );
  s += uint32_t( vgmStream.getc() ) << ( 8 * 2 );
  s += uint32_t( vgmStream.getc() ) << ( 8 * 3 );
  pcmPosition = s;
  DEBUG_PRINTLN( "Seeking PCM Pointer to Offset " + String( pcmPosition, HEX ));
}

void badCommand( uint8_t command, uint32_t debugAddress ) {
  Serial.println( "Error: Unknown Command 0x" + String( command, HEX ) + " @ 0X" + String( debugAddress, HEX ));
  nextSongFlag = 1;
}

void silence() {
  playSNdata( 0x9F ); //4 byte silence sn sequence
  playSNdata( 0xBF );
  playSNdata( 0xDF );
  playSNdata( 0xFF );
  playYMdata( 0, 0x22, 0x00 ); // LFO off
  playYMdata( 0, 0x27, 0x00 ); // Note off (channel 0)
  playYMdata( 0, 0x28, 0x01 ); // Note off (channel 1)
  playYMdata( 0, 0x28, 0x02 ); // Note off (channel 2)
  playYMdata( 0, 0x28, 0x04 ); // Note off (channel 3)
  playYMdata( 0, 0x28, 0x05 ); // Note off (channel 4)
  playYMdata( 0, 0x28, 0x06 ); // Note off (channel 5)
  playYMdata( 0, 0x2B, 0x00 ); // DAC off
  playYMdata( 0, 0x30, 0x71 ); //
  playYMdata( 0, 0x34, 0x0D ); //
  playYMdata( 0, 0x38, 0x33 ); //
  playYMdata( 0, 0x3C, 0x01 ); // DT1/MUL
  playYMdata( 0, 0x40, 0x23 ); //
  playYMdata( 0, 0x44, 0x2D ); //
  playYMdata( 0, 0x48, 0x26 ); //
  playYMdata( 0, 0x4C, 0x00 ); // Total level
  playYMdata( 0, 0x50, 0x5F ); //
  playYMdata( 0, 0x54, 0x99 ); //
  playYMdata( 0, 0x58, 0x5F ); //
  playYMdata( 0, 0x5C, 0x94 ); // RS/AR
  playYMdata( 0, 0x60, 0x05 ); //
  playYMdata( 0, 0x64, 0x05 ); //
  playYMdata( 0, 0x68, 0x05 ); //
  playYMdata( 0, 0x6C, 0x07 ); // AM/D1R
  playYMdata( 0, 0x70, 0x02 ); //
  playYMdata( 0, 0x74, 0x02 ); //
  playYMdata( 0, 0x78, 0x02 ); //
  playYMdata( 0, 0x7C, 0x02 ); // D2R
  playYMdata( 0, 0x80, 0x11 ); //
  playYMdata( 0, 0x84, 0x11 ); //
  playYMdata( 0, 0x88, 0x11 ); //
  playYMdata( 0, 0x8C, 0xA6 ); // D1L/RR
  playYMdata( 0, 0x90, 0x00 ); //
  playYMdata( 0, 0x94, 0x00 ); //
  playYMdata( 0, 0x98, 0x00 ); //
  playYMdata( 0, 0x9C, 0x00 ); // Proprietary
  playYMdata( 0, 0xB0, 0x32 ); // Feedback/algorithm
  playYMdata( 0, 0xB4, 0xC0 ); // Both speakers on
  playYMdata( 0, 0x28, 0x00 ); // Key off
}

jumpTable vgmFunctions[ 256 ] = { nogo, nogo, nogo, nogo, nogo, nogo, nogo, nogo, nogo, nogo, nogo, nogo, nogo, nogo, nogo, nogo, nogo, nogo, nogo, nogo, nogo, nogo, nogo, nogo, nogo, nogo, nogo, nogo, nogo, nogo, nogo, nogo, nogo, nogo, nogo, nogo, nogo, nogo, nogo, nogo, nogo, nogo, nogo, nogo, nogo, nogo, nogo, nogo, nogo, nogo, nogo, nogo, nogo, nogo, nogo, nogo, nogo, nogo, nogo, nogo, nogo, nogo, nogo, nogo, nogo, nogo, nogo, nogo, nogo, nogo, nogo, nogo, nogo, nogo, nogo, nogo, nogo, nogo, nogo, nogo, playSN, playSN, playYM0, playYM1, nogo, nogo, nogo, nogo, nogo, nogo, nogo, nogo, nogo, nogo, nogo, nogo, nogo, waitSamples, wait735Samples, wait882Samples, nogo, nogo, endOfFile, pcmStream, nogo, nogo, nogo, nogo, nogo, nogo, nogo, nogo, wait1Samples, wait2Samples, wait3Samples, wait4Samples, wait5Samples, wait6Samples, wait7Samples, wait8Samples, wait9Samples, wait10Samples, wait11Samples, wait12Samples, wait13Samples, wait14Samples, wait15Samples, wait16Samples, play0Sample, play1Sample, play2Sample, play3Sample, play4Sample, play5Sample, play6Sample, play7Sample, play8Sample, play9Sample, play10Sample, play11Sample, play12Sample, play13Sample, play14Sample, play15Sample, nogo, nogo, nogo, nogo, nogo, nogo, nogo, nogo, nogo, nogo, nogo, nogo, nogo, nogo, nogo, nogo, nogo, nogo, nogo, nogo, nogo, nogo, nogo, nogo, nogo, nogo, nogo, nogo, nogo, nogo, nogo, nogo, nogo, nogo, nogo, nogo, nogo, nogo, nogo, nogo, nogo, nogo, nogo, nogo, nogo, nogo, nogo, nogo, nogo, nogo, nogo, nogo, nogo, nogo, nogo, nogo, nogo, nogo, nogo, nogo, nogo, nogo, nogo, nogo, nogo, nogo, nogo, nogo, nogo, nogo, nogo, nogo, nogo, nogo, nogo, nogo, nogo, nogo, nogo, nogo, seekPCM, nogo, nogo, nogo, nogo, nogo, nogo, nogo, nogo, nogo, nogo, nogo, nogo, nogo, nogo, nogo, nogo, nogo, nogo, nogo, nogo, nogo, nogo, nogo, nogo, nogo, nogo, nogo, nogo, nogo, nogo, nogo };
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
void loop() {
  String fileNameString;

  randomSeed( micros() );
  uint16_t randomFile = random( numFiles - 1 );
  DEBUG_PRINTLN( "Opening File Number: " + String( randomFile ));
  SD.vwd()->rewind();
  vgmFile.openNext( SD.vwd(), O_READ );
  for ( int i = 0; i < randomFile; i++ ) {
    vgmFile.close();
    vgmFile.openNext( SD.vwd(), O_READ );
  }
  fileNameString = vgmFile.getName( fileNameBuf, sizeof( fileNameBuf ));
  vgmFile.close();

  //fileNameString = "Sonic Spinball - Lava Power House (2)"; fileNameString.toCharArray( fileNameBuf, 256 );
  //fileNameString = "Sonic 3 & Knuckles - Angel Island Zone 1"; fileNameString.toCharArray( fileNameBuf, 256 );
  //fileNameString = "Sonic 3 & Knuckles - Carnival Night Zone 1"; fileNameString.toCharArray( fileNameBuf, 256 );

  Serial.println( "Opening VGM File " + String( fileNameBuf ));
  display.clearDisplay();
  display.setTextSize(1);
  display.setTextColor(WHITE);
  display.setCursor(0, 0);
  display.println("Now Playing");
  display.println(String( fileNameBuf ));
  display.display();
  if ( vgmStream.fopen( fileNameBuf , "r" )) {
    ramBufferFlag = 0;
    vgmStreamPosition = 0;
    pcmPosition = 0;
    pcmPositionOffset = 0;
    ident = 0;
    eof = 0;
    vers = 0;
    snclk = 0;
    ymclk = 0;
    gd3Offset = 0;
    totalSamples = 0;
    loopOffset = 0;
    loopSamples = 0;
    rateHz = 0;
    snFeedback = 0;
    snShiftReg = 0;
    snFlags = 0;
    ym2612Clock = 0;
    ym2151Clock = 0;
    vgmDataOffset = 0;
    for ( int i = 0; i < 4; i++ ) ident += uint32_t(vgmStream.getc()) << ( 8 * i );
    for ( int i = 0; i < 4; i++ ) eof += uint32_t(vgmStream.getc()) << ( 8 * i );
    for ( int i = 0; i < 4; i++ ) vers += uint32_t(vgmStream.getc()) << ( 8 * i );
    for ( int i = 0; i < 4; i++ ) snclk += uint32_t(vgmStream.getc()) << ( 8 * i );
    for ( int i = 0; i < 4; i++ ) ymclk += uint32_t(vgmStream.getc()) << ( 8 * i );
    for ( int i = 0; i < 4; i++ ) gd3Offset += uint32_t(vgmStream.getc()) << ( 8 * i );
    for ( int i = 0; i < 4; i++ ) totalSamples += uint32_t(vgmStream.getc()) << ( 8 * i );
    for ( int i = 0; i < 4; i++ ) loopOffset += uint32_t(vgmStream.getc()) << ( 8 * i );
    for ( int i = 0; i < 4; i++ ) loopSamples += uint32_t(vgmStream.getc()) << ( 8 * i );
    for ( int i = 0; i < 4; i++ ) rateHz += uint32_t(vgmStream.getc()) << ( 8 * i );
    for ( int i = 0; i < 4; i++ ) snFeedback += uint32_t(vgmStream.getc()) << ( 8 * i );
    for ( int i = 0; i < 4; i++ ) snShiftReg += uint32_t(vgmStream.getc()) << ( 8 * i );
    for ( int i = 0; i < 4; i++ ) snFlags += uint32_t(vgmStream.getc()) << ( 8 * i );
    for ( int i = 0; i < 4; i++ ) ym2612Clock += uint32_t(vgmStream.getc()) << ( 8 * i );
    for ( int i = 0; i < 4; i++ ) ym2151Clock += uint32_t(vgmStream.getc()) << ( 8 * i );
    for ( int i = 0; i < 4; i++ ) vgmDataOffset += uint32_t(vgmStream.getc()) << ( 8 * i );
    if ( ident != 0x206d6756 ) {
      Serial.println( "Ident Match Failed! " + String( ident, HEX ) );
      return;
    }
    if (( vgmDataOffset == 0x40 ) || ( vgmDataOffset == 0x00 )) vgmStream.fseek( 0x40, SEEK_SET );
    else vgmStream.fseek( vgmDataOffset, SEEK_SET );
    DEBUG_PRINTLN( "--------------VGM File Data Start--------------" );
    nextButtonFlag = 0;
    nextSongFlag = 0;
    while ( ( nextSongFlag == 0 ) && ( nextButtonFlag == 0 )) {
      if ( playButtonFlag ) {
        display.clearDisplay();
        display.setCursor(0, 0);
        display.println("Paused");
        display.println(String( fileNameBuf ));
        display.display();
        delay( 100 );
        playButtonFlag = 0;
        while ( !playButtonFlag ) ;
        display.clearDisplay();
        display.setCursor(0, 0);
        display.println("Now Playing");
        display.println("");
        display.println(String( fileNameBuf ));
        display.display();
        delay( 100 );
        playButtonFlag = 0;
      }
      //int32_t debugAddress = 0; // vgmStream.ftell();
      uint8_t command = vgmStream.getc();
      //DEBUG_PRINT( "Addr:0x" + String( debugAddress, HEX ) + " Cmd:0x" + String( command, HEX ) + " | " );
      vgmFunctions[ command ]();
      while ( pause );
    }
  }
  else Serial.println( "Cannot open " + String( fileNameBuf ) + ": File read error" );
  PORT->Group[PORTA].OUTSET.reg = MEM_CS;
  PORT->Group[PORTA].OUTSET.reg = HOLD;
  vgmStream.fclose();
  PORT->Group[PORTA].OUTCLR.reg = YM_IC | MEM_CS;
  delay( 10 );
  PORT->Group[PORTA].OUTSET.reg = YM_IC | MEM_CS;
  delay( 10 );
  silence();
  Serial.println( "Next" );
}

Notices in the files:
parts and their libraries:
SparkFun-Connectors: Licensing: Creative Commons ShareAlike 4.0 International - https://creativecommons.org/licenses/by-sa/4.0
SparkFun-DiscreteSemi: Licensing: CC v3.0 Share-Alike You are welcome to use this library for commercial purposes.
